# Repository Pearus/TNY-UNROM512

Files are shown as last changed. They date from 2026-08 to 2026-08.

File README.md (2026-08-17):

# TNY-UNROM512

This is a custom UNROM512 board for the TinyTendo handheld console by <a href="https://github.com/Redherring32">Redherring32</a>. This board replicates <a href="https://www.nesdev.org/wiki/UNROM_512">standard UNROM 512 NES boards</a>. 

Since these boards use the 39SF040 for the PRG ROM, you should use FamiROM or some other utility to duplicate the ROM files to completely fill up the entire space on the Flash chip if necessary.

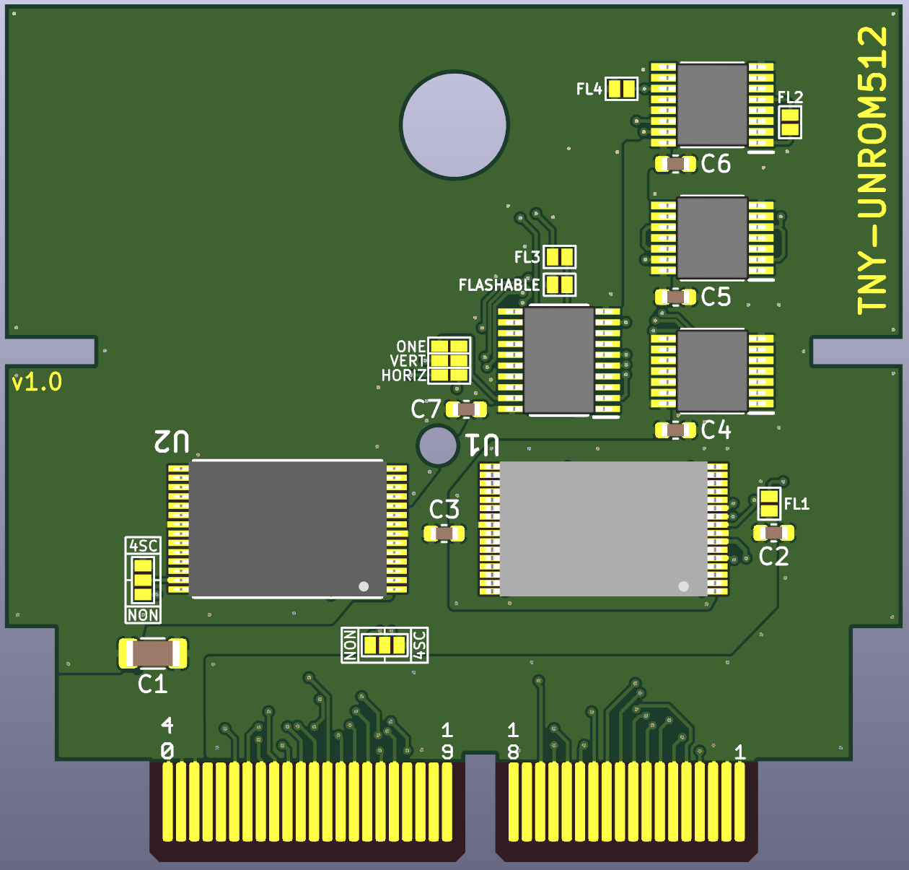
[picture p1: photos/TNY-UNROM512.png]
Populated TNY-UNROM512 Board


# TNY-UNROM512 Board Characteristics

- Thickness: 1.6 mm
- Surface Finish: ENIG
- Chamfered edges (45°)

# How to Use This Board

*Note: Do not solder U1 to the board before programming it.*

UNROM512 games require every component on the board.

The solder jumpers must be bridged according to the NES game you program.

## Flashing the Game

Prepare the ROM using FamiROM or other similar program, ensuring the entire 4Mbit space is filled for the PRG component. You then need to program the 39SF040 before soldering it to the board. I use a <a href="https://www.embeddedcomputers.net/products/FlashcatUSB_XPORT/">FlashCat</a> with a <a href="https://www.embeddedcomputers.net/products/ParallelAdapters/">TSOP-32 adapter (Type B)</a> to achieve this.

# Bill of Materials

Capacitors should be at least 16V rated.

| Reference Designator  | Part Number/Value | Footprint  |
| --- | --- | --- |
| C1  | 22 uF | 1206  |
| C2-C7  | 0.1 uF | 0603  |
| U1  | <a href="https://www.mouser.com/ProductDetail/Microchip-Technology/SST39SF040-70-4C-WHE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">39SF040</a>  | TSOP32 (14mm) |
| U2  | <a href="https://www.mouser.com/ProductDetail/Alliance-Memory/AS6C6264-55STCN?qs=LD2UibpCYJonFY2RVods7g%3D%3D">AS6C6264</a> or <a href="https://www.mouser.com/ProductDetail/870-IS61C64AL-10TLI">IS61C64AL-10TLI</a>  | TSOP28 |
| U3  | <a href="https://www.mouser.com/en/ProductDetail/Texas-Instruments/SN74HC32PWR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">SN74HC32PWR</a> | TSSOP14 |
| U4  | <a href="https://www.mouser.com/en/ProductDetail/Texas-Instruments/SN74HC32PWR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">SN74HC32PWR</a> | TSSOP14 |
| U5  | <a href="https://www.mouser.com/en/ProductDetail/Texas-Instruments/SN74HC139PWR?qs=%252BWCn1GN4mVzsIRktqzW%252B6w%3D%3D">SN74HC139PWR</a> | TSSOP16 |
| U6  | <a href="https://www.mouser.com/en/ProductDetail/Texas-Instruments/SN74HC377DWR?qs=VolsR0DjNPqmUtsQyZQkhw%3D%3D">SN74HC377DWR</a> | SOIC20 |

# Revision History

## v1.0

- Initial version

## License
<br />This work is licensed under a <a rel="license" href="http://creativecommons.org/licenses/by-sa/4.0/">Creative Commons Attribution-ShareAlike 4.0 International License</a>. You are able to copy and redistribute the material in any medium or format, as well as remix, transform, or build upon the material for any purpose (even commercial) - but you **must** give appropriate credit, provide a link to the license, and indicate if any changes were made.

## Credits

*Redherring32* - Creating the TinyTendo project.

*BucketMouse* - Original MMC3 and NROM cartridge designs for TinyTendo which this is an extension of.

*NESDev* - Wiki was heavily referenced as part of writing the schematic and troubleshooting.

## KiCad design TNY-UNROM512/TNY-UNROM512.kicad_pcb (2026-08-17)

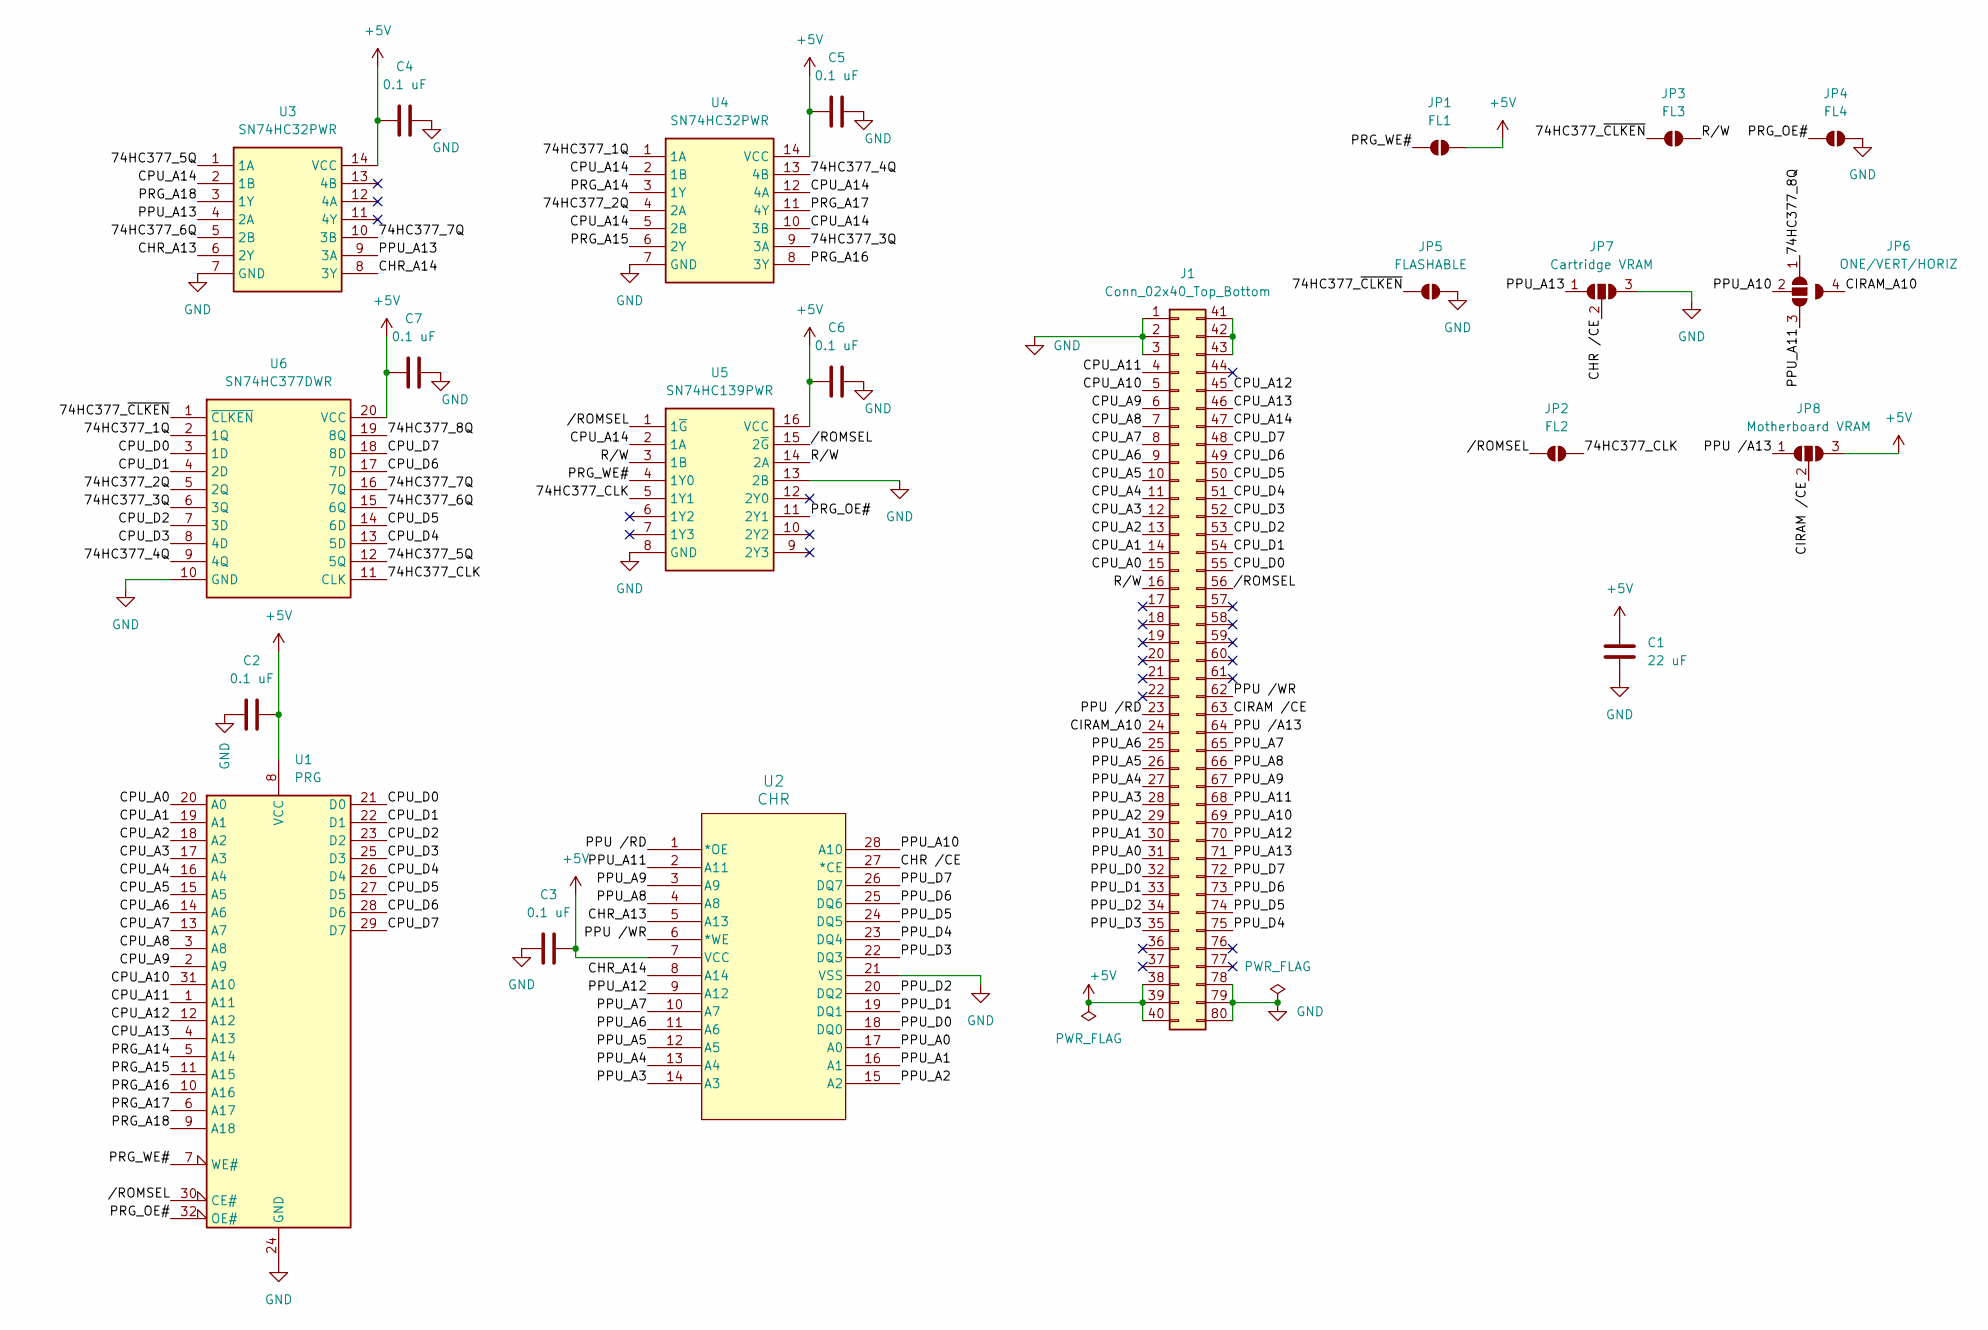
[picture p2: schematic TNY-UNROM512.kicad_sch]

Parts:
C1: 22 uF; C_1206_3216Metric
C2, C3, C4, C5, C6, C7: 0.1 uF; C_0603_1608Metric
J1: Conn_02x40_Top_Bottom; TNY-UNROM512 Edge Connector
JP1: FL1; Jumper
JP2: FL2; Jumper
JP3: FL3; Jumper
JP4: FL4; Jumper
JP5: FLASHABLE; Jumper
JP6: ONE/VERT/HORIZ; CIRAM_A10 Jumper
JP7: Cartridge VRAM; Screen Jumper
JP8: Motherboard VRAM; Screen Jumper
U1: PRG; TSOP-32
U2: CHR; TSOP-28
U3, U4: SN74HC32PWR; Mouser Part Number 595-SN74HC32PWR
U5: SN74HC139PWR; Mouser Part Number 595-SN74HC139PWR
U6: SN74HC377DWR; Mouser Part Number 595-SN74HC377DWR

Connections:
+5V: C1.1, C2.2, C3.1, C4.2, C5.2, C6.2, C7.2, J1.38, J1.39, J1.40, JP1.2 (B), JP8.3 (B), U1.8 (VCC), U2.7 (VCC), U3.14 (VCC), U4.14 (VCC), U5.16 (VCC), U6.20 (VCC)
/74HC377_1Q: U4.1 (1A), U6.2 (1Q)
/74HC377_2Q: U4.4 (2A), U6.5 (2Q)
/74HC377_3Q: U4.9 (3A), U6.6 (3Q)
/74HC377_4Q: U4.13 (4B), U6.9 (4Q)
/74HC377_5Q: U3.1 (1A), U6.12 (5Q)
/74HC377_6Q: U3.5 (2B), U6.15 (6Q)
/74HC377_7Q: U3.10 (3B), U6.16 (7Q)
/74HC377_8Q: JP6.1 (A), U6.19 (8Q)
/74HC377_CLK: JP2.2 (B), U5.5 (1Y1), U6.11 (CLK)
/74HC377_~CLKEN: JP3.1 (A), JP5.1 (A), U6.1 (~CLKEN)
/CHR /CE: JP7.2 (C), U2.27 (*CE)
/CHR_A13: U2.5 (A13), U3.6 (2Y)
/CHR_A14: U2.8 (A14), U3.8 (3Y)
/CIRAM /CE: J1.63, JP8.2 (C)
/CIRAM_A10: J1.24, JP6.4 (A)
/CPU_A0: J1.15, U1.20 (A0)
/CPU_A1: J1.14, U1.19 (A1)
/CPU_A2: J1.13, U1.18 (A2)
/CPU_A3: J1.12, U1.17 (A3)
/CPU_A4: J1.11, U1.16 (A4)
/CPU_A5: J1.10, U1.15 (A5)
/CPU_A6: J1.9, U1.14 (A6)
/CPU_A7: J1.8, U1.13 (A7)
/CPU_A8: J1.7, U1.3 (A8)
/CPU_A9: J1.6, U1.2 (A9)
/CPU_A10: J1.5, U1.31 (A10)
/CPU_A11: J1.4, U1.1 (A11)
/CPU_A12: J1.45, U1.12 (A12)
/CPU_A13: J1.46, U1.4 (A13)
/CPU_A14: J1.47, U3.2 (1B), U4.2 (1B), U4.5 (2B), U4.10 (3B), U4.12 (4A), U5.2 (1A)
/CPU_D0: J1.55, U1.21 (D0), U6.3 (1D)
/CPU_D1: J1.54, U1.22 (D1), U6.4 (2D)
/CPU_D2: J1.53, U1.23 (D2), U6.7 (3D)
/CPU_D3: J1.52, U1.25 (D3), U6.8 (4D)
/CPU_D4: J1.51, U1.26 (D4), U6.13 (5D)
/CPU_D5: J1.50, U1.27 (D5), U6.14 (6D)
/CPU_D6: J1.49, U1.28 (D6), U6.17 (7D)
/CPU_D7: J1.48, U1.29 (D7), U6.18 (8D)
/PPU /A13: J1.64, JP8.1 (A)
/PPU /RD: J1.23, U2.1 (*OE)
/PPU /WR: J1.62, U2.6 (*WE)
/PPU_A0: J1.31, U2.17 (A0)
/PPU_A1: J1.30, U2.16 (A1)
/PPU_A2: J1.29, U2.15 (A2)
/PPU_A3: J1.28, U2.14 (A3)
/PPU_A4: J1.27, U2.13 (A4)
/PPU_A5: J1.26, U2.12 (A5)
/PPU_A6: J1.25, U2.11 (A6)
/PPU_A7: J1.65, U2.10 (A7)
/PPU_A8: J1.66, U2.4 (A8)
/PPU_A9: J1.67, U2.3 (A9)
/PPU_A10: J1.69, JP6.2 (C), U2.28 (A10)
/PPU_A11: J1.68, JP6.3 (B), U2.2 (A11)
/PPU_A12: J1.70, U2.9 (A12)
/PPU_A13: J1.71, JP7.1 (A), U3.4 (2A), U3.9 (3A)
/PPU_D0: J1.32, U2.18 (DQ0)
/PPU_D1: J1.33, U2.19 (DQ1)
/PPU_D2: J1.34, U2.20 (DQ2)
/PPU_D3: J1.35, U2.22 (DQ3)
/PPU_D4: J1.75, U2.23 (DQ4)
/PPU_D5: J1.74, U2.24 (DQ5)
/PPU_D6: J1.73, U2.25 (DQ6)
/PPU_D7: J1.72, U2.26 (DQ7)
/PRG_A14: U1.5 (A14), U4.3 (1Y)
/PRG_A15: U1.11 (A15), U4.6 (2Y)
/PRG_A16: U1.10 (A16), U4.8 (3Y)
/PRG_A17: U1.6 (A17), U4.11 (4Y)
/PRG_A18: U1.9 (A18), U3.3 (1Y)
/PRG_OE#: JP4.1 (A), U1.32 (OE#), U5.11 (2Y1)
/PRG_WE#: JP1.1 (A), U1.7 (WE#), U5.4 (1Y0)
/R/W: J1.16, JP3.2 (B), U5.3 (1B), U5.14 (2A)
//ROMSEL: J1.56, JP2.1 (A), U1.30 (CE#), U5.1 (1~G), U5.15 (2~G)
GND: C1.2, C2.1, C3.2, C4.1, C5.1, C6.1, C7.1, J1.1, J1.2, J1.3, J1.78, J1.79, J1.80, JP4.2 (B), JP5.2 (B), JP7.3 (B), U1.24 (GND), U2.21 (VSS), U3.7 (GND), U4.7 (GND), U5.8 (GND), U5.13 (2B), U6.10 (GND)
unnamed: J1.41, J1.42, J1.43

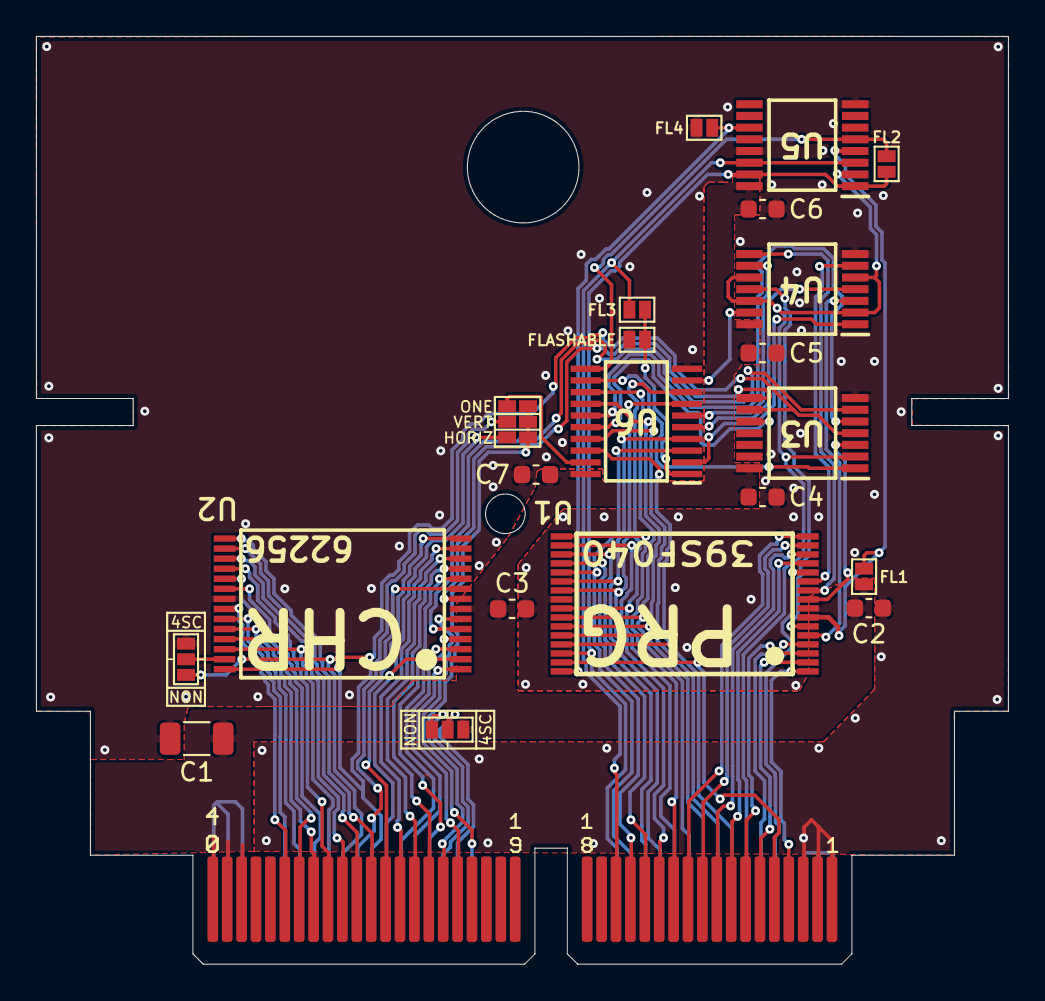
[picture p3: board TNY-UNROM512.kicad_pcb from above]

Board: 2 copper layers, 54.0 x 51.5 mm, 22 parts (0 on the bottom side), 75 nets.
